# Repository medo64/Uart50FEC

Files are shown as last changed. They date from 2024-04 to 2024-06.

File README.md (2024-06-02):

[UART 5V Framework Expansion Card](https://medo64.com/uart50fec/)
=================================================================

This Framework laptop expansion card will show up on your system as a serial
device and allow for a non-isolated serial UART communication up to 1 Mbaud
baud rate.

Please note that this card is not using RS-232 but 5V TTL.

## UART Pinout

To connect to this board, one has to use a 4-pin JST XH connector. The following
table represents the pinout, pin 1 being on the left as looking into the
expansion card.

| # | Ref | Description |
|--:|:---:|---|
| 1 | GND | Ground connection |
| 2 | RXD | Receive (5V TTL) |
| 3 | TXD | Transmit (5V TTL) |
| 4 | 5V  | 5V 500mA output (typical) |

Using 22 AWG wire 0.25 mm² is recommended.

## Supported Speeds

This board employs the FT232R as its UART chip, and consequently, it supports
all the baud rates this chip [can handle](https://ftdichip.com/Documents/AppNotes/AN232B-05_BaudRates.pdf).
The table below lists the standard baud rates.

| Baud rate | Actual | Error | Divisor |
|---:|---:|---:|---:|
| 300 | 300 | 0.00% |  10000.000 |
| 600 | 600 | 0.00% | 5000.000 |
| 1,200 | 1,200 | 0.00% | 2500.000 |
| 1,800 | 1,800 | 0.00% | 1666.625 |
| 2,400 | 2,400 | 0.00% | 1250.000 |
| 4,800 | 4,800 | 0.00% | 625.000 |
| 7,200 | 7,201 | 0.01% | 416.625 |
| 9,600 | 9,600 | 0.00% | 312.500 |
| 14,400 | 14,406 | 0.04% | 208.250 |
| 19,200 | 19,200 | 0.00% | 156.250 |
| 28,800 | 28,812 | 0.04% | 104.125 |
| 38,400 | 38,400 | 0.00% | 78.125 |
| 57,600 | 57,692 | 0.16% | 52.000 |
| 115,200 | 115,385 | 0.16% | 26.000 |
| 230,400 | 230,769 | 0.16% | 13.000 |
| 460,800 | 461,538 | 0.16% | 6.500 |
| 921,600 | 923,077 | 0.16% | 3.250 |
| 1,000,000 | 1,000,000 | 0.00% | 3.000 |

While chip does support baud rates up to 3 Mbaud, granularity of such rates
is severely limited.

---
*You can check my blog and other projects at [www.medo64.com](https://www.medo64.com/electronics/).*

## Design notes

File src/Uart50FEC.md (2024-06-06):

### Uart50FEC

#### Parts

|  # | Part | RefDes  | Preferred Part Number |
|---:|---|---|---|
|  1 | C 10nF X7R 16V (0805) | C1 | 399-17617-1-ND |
|  4 | C 100nF X7R 16V (0805) | C2-C5 | 478-5311-1-ND |
|  3 | C 10uF X5R 16V (0805) | C6-C8 | 490-18664-1-ND |
|  1 | D Schottky 30V 800mA [CUS08F30,H3F] (SOD323) | D1 | CUS08F30H3FCT-ND |
|  1 | D TVS 5V SM05T1G (SOT23-3) | D2 | SM05T1GOSCT-ND |
|  2 | DS LED (0805) | DS1-DS2 | 475-1415-1-ND |
|  1 | J USB C, plug, straddle 0.8mm | J1 | WM12855-ND |
|  1 | J JST XH Vertical (4w) | J2 | 455-B4B-XH-A-ND |
|  1 | L Ferrite 600R@100Mhz | L1 | 240-2390-1-ND |
|  3 | R 1K 0.125W (0805) | R1-R3 | RMCF0805FT1K00CT-ND |
|  1 | R 5.1K 0.125W (0805) | R4 | RMCF0805FT5K10CT-ND |
|  1 | R 10K 0.125W (0805) | R5 | RMCF0805FT10K0CT-ND |
|  1 | R 75K 0.125W (0805) | R6 | RMCF0805FT75K0CT-ND |
|  1 | U Transciever Uart [FT232R] (SSOP-28) | U1 | 768-FT232RNL-TUBE-ND |
|  1 | U LoadSwitch Adjustable [AP22652W6-7] (SOT23-6) | U2 | 31-AP22652W6-7CT-ND |
|  2 | H Screw M2x3mm | - | - |

#### Specifications

| Property | Value |
|---|---|
| PCB size | 24.0 x 27.9 x 0.8 mm (1.1 in²) |
| Voltage (in) | 5 V ±10% |
| Current (in) | 450 mA (max) |
| Voltage (out) | 5 V ±15% |
| Current (limit) | 400 mA ±10% |

#### FTDI Configuration

| Setting | Value  |
|---|---|
| CBUS0 | TXLED# |
| CBUS1 | RXLED# |
| CBUS2 | TXDEN  |
| CBUS3 | PWREN# |
| CBUS4 | SLEEP# |

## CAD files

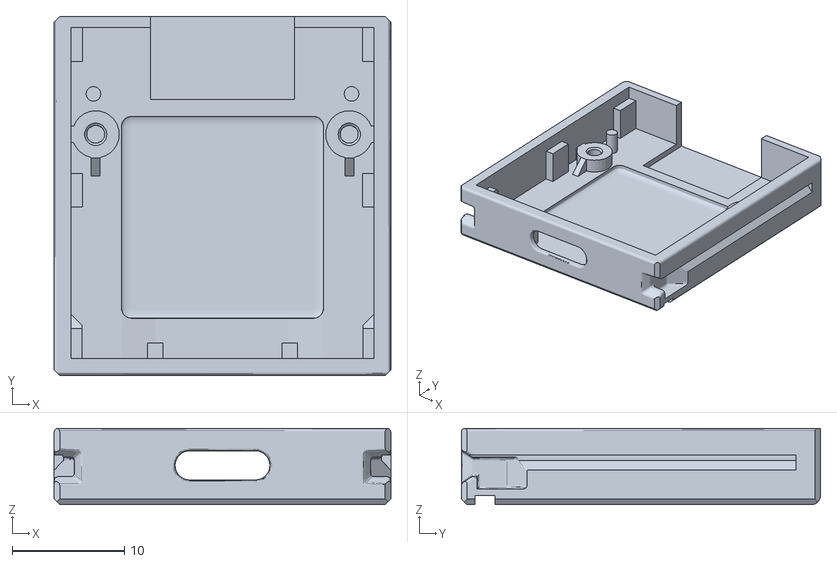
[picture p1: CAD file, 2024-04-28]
src/case/Uart50FEC Case Base.stl
30.0 x 32.0 x 6.80

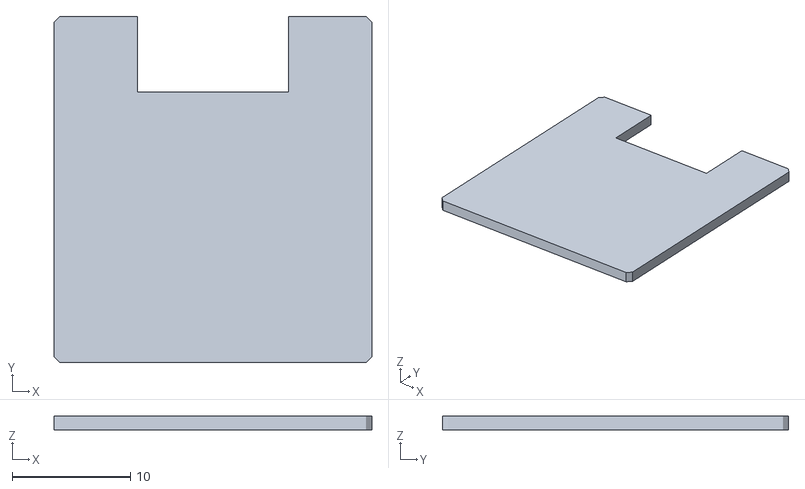
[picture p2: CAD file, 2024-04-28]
src/case/Uart50FEC Case Top.stl
26.9 x 29.3 x 1.20

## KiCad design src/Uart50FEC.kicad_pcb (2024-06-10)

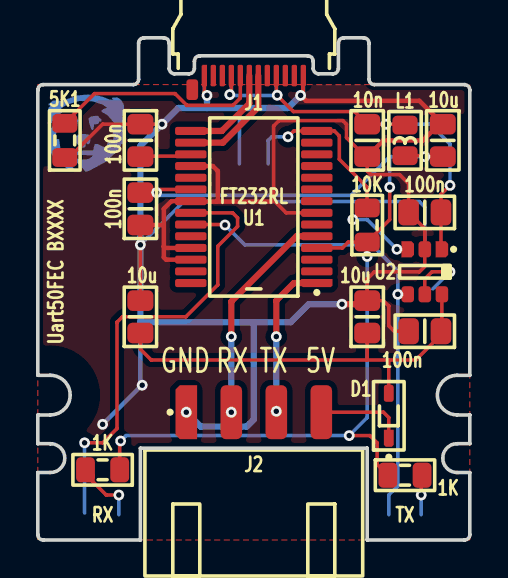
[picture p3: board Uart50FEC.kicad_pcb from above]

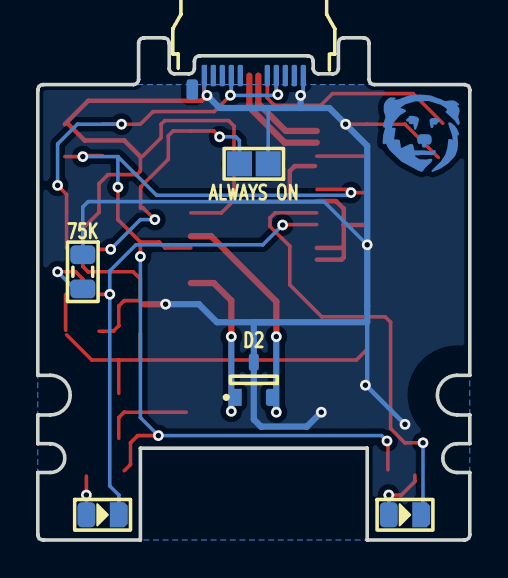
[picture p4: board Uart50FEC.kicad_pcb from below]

Board: 2 copper layers, 24.0 x 27.9 mm, 24 parts (6 on the bottom side), 17 nets.

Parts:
C1: 10n; C (0805)
C2, C3, C4, C5: 100n; C (0805)
C6, C7, C8: 10u; C (0805)
D1: CUS08F30; D (SOD323)
D2: SM05T1G; D TVS 5V [SM05T1G] (SOT23-3)
DS1: RX; DS (0805)
DS2: TX; DS (0805)
ICON: Medo64; ICON Medo64
J1: 105444-0001; J USB C 3.2 Edge (24w)
J2: B4B-XH-A; J JST XH Edge [UART] (4w)
JP1: ALWAYS ON; JP (0805)
L1: 600R; L (0805)
R1, R2: 1K; R (0805)
R3: 5K1; R (0805)
R4: 10K; R (0805)
R5: 75K; R (0805)
U1: FT232RL; U Transceiver UART [FT232R] (SSOP-28)
U2: MIC2005A-1; U LoadSwitch Adjustable [AP22652W6-7] (SOT23-6)

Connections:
3V3_UART_USB: C3.2, U1.17
5V: C2.2, C6.2, L1.1, R1.1, R2.1, R4.1, U1.4, U1.20
5V_OUT: D1.1, J2.4
5V_SWITCHED: C5.1, C7.1, C8.1, D1.2, U2.6
5V_USB: C1.2, C4.1, J1.A4, J1.A9, J1.B04, J1.B09, L1.2, U2.1
A_CC: J1.A5, R3.2
GND: C1.1, C2.1, C3.1, C4.2, C5.2, C6.1, C7.2, C8.2, D2.3, J1.A1, J1.A12, J1.B01, J1.B12, J2.1, JP1.2, R3.1, R5.2, U1.7, U1.18, U1.21, U1.25, U1.26, U2.2
ILIM: R5.1, U2.5
LED_RX#: DS1.1, U1.22
LED_RXD': DS1.2, R1.2
LED_TX#: DS2.1, U1.23, U2.4
LED_TXD': DS2.2, R2.2
PWREN#: JP1.1, R4.2, U1.14, U2.3
RXD: D2.2, J2.2, U1.5
TXD: D2.1, J2.3, U1.1
USB_DM: J1.A7, U1.16
USB_DP: J1.A6, U1.15

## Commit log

2024-05-11 Updated type-C connector to allow for more soldermask
    [Uart50FEC.kicad_pcb]
2024-06-02 Fixed max power
2024-06-02 Changed pinout
    [Uart50FEC.kicad_pcb]
2024-06-06 More output capacitance
    [Uart50FEC.kicad_pcb]
2024-06-06 Swapped load switch
    [Uart50FEC.kicad_pcb]
2024-06-06 Added jumper for always on
    [Uart50FEC.kicad_pcb]
2024-06-06 Lowering output current a bit
    [Uart50FEC.kicad_pcb]
2024-06-10 Fixed output enable
    [Uart50FEC.kicad_pcb]
2024-06-10 Updated net names
    [Uart50FEC.kicad_pcb]
